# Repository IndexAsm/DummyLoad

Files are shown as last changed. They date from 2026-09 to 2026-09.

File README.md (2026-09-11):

# Electronic Load
A high-power, water-cooled electronic load designed for testing power supplies, batteries, converters, and other high-power electronics.

## [Board Preview]([https://kicanvas.org/?repo=https%3A%2F%2Fgithub.com%2FIndexAsm%2FDummyLoad](https://kicanvas.org/?repo=https%3A%2F%2Fgithub.com%2FIndexAsm%2FDummyLoad%2Ftree%2Fmain%2FPCB))
Note: There is a bug in the preview. It displays components from the control board next to power board, even though they are deleted in the project.

## Features
* **2 kW maximum power**
* **60 V maximum input voltage**
* **50 A maximum load current**
* **Water-cooled power stage**
* Constant-current (CC) regulation
* Multiple current ranges for improved resolution
* Designed for continuous high-power operation
* Custom-built control and measurement electronics

## Specifications

| Parameter | Specification |
| --- | ---: |
| Maximum Power | **2 kW** |
| Maximum Voltage | **60 V** |
| Maximum Current | **50 A** |
| Cooling | **Water cooling** |
| Regulation Mode | **Constant Current (CC)** |

### CC Regulation Ranges

| Current Range | Resolution |
| ---: | ---: |
| 0–50 A | 100 mA |
| 0–10 A | 25 mA |
| 0–5 A | 10 mA |

The selectable current ranges provide finer control at lower currents while maintaining the full **50 A** capability when required.

## Functions

* **Constant-current load (CC)**
* Selectable current ranges
* Input voltage measurement
* Load current measurement
* Power measurement
* Water-cooling system
* High-power continuous-load operation

## Applications

This electronic load is intended for testing:

* Linear and switching power supplies
* DC-DC converters
* Battery systems
* USB power supplies
* High-current power sources
* Custom power electronics

## [BOM](BOM.csv)
Total is around 600zł -> 160$

## Gallery
obraz
obraz

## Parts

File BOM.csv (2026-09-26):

Reference | Qty | Value | Price | Footprint | Link | DNP
C1,C3,C5,C14,C15,C17,C18,C21,C22,C23,C24,C25,C26,C28,C29,C30,C31,C32,C33,C36,C37,C40,C41,C42,C43,C44,C47,C48,C53,C54,C56,C58,C59 | 33 | 100n |  | Capacitor_SMD:C_0603_1608Metric
C2,C19,C27,C39 | 4 | 2u2 |  | Capacitor_SMD:C_0603_1608Metric
C4,C20 | 2 | 100u |  | Capacitor_THT:C_Radial_D6.3mm_H7.0mm_P2.50mm
C6,C62 | 2 | 22u | 4.10 | Capacitor_SMD:C_1206_3216Metric | https://www.tme.eu/pl/details/grm31cr61e226ke15l/kondensatory-mlcc-smd/murata/
C7 | 1 | 100n | 2.45 | Capacitor_THT:C_Disc_D11.0mm_W5.0mm_P10.00mm | https://www.tme.eu/pl/en/details/cc-104_500/ceramic-capacitors/sr-passives/
C8,C9,C10 | 3 | 1n |  | Capacitor_SMD:C_0603_1608Metric
C11,C12,C13 | 3 | 10n |  | Capacitor_SMD:C_0603_1608Metric
C16,C63,C64 | 3 | 100n |  | Capacitor_SMD:C_0603_1608Metric | https://www.tme.eu/pl/details/grm188r60j226mea0d/kondensatory-mlcc-smd/murata/
C34,C35 | 2 | 12p |  | Capacitor_SMD:C_0603_1608Metric
C38 | 1 | 10u | 1,51zł | Capacitor_SMD:C_0805_2012Metric | https://www.mouser.pl/en/ProductDetail/Samsung-Electro-Mechanics/CL21A106KOQNNNF
C45,C46,C49,C50,C51,C52,C55,C57,C60 | 9 | 22u | 9.83 | Capacitor_SMD:C_1206_3216Metric | https://www.tme.eu/pl/en/details/msast31lbb5226mtna/mlcc-smd-capacitors/taiyo-yuden/msast31lbb5226mtna01/
C61 | 1 | 22n |  | Capacitor_SMD:C_0603_1608Metric | https://www.tme.eu/pl/details/cc0603krx7r9bb223/kondensatory-mlcc-smd/yageo/
D1,D2 | 2 | 1N4148W |  | Diode_SMD:D_SOD-123
FB1,FB2 | 2 | 220R |  | Inductor_SMD:L_0603_1608Metric
FB3 | 1 | 120R |  | Inductor_SMD:L_0603_1608Metric
J1 | 8 | YK3030423000G | 57.07 | TerminalBlock_MetzConnect:TerminalBlock_MetzConnect_Type175_RT02704HBLC_1x04_P7.50mm_Horizontal | https://www.tme.eu/pl/en/details/yk3030423000g/terminal-blocks/amphenol-anytek/
J3,J4,J5,J6,J7 | 5 | Conn_01x10 |  | Connector_PinHeader_2.54mm:PinHeader_1x10_P2.54mm_Vertical
J8 | 1 | Conn_01x14 |  | Connector_PinHeader_2.54mm:PinHeader_1x14_P2.54mm_Vertical
J9,J11 | 2 | Conn_01x04 |  | Connector_PinHeader_2.54mm:PinHeader_1x04_P2.54mm_Vertical
J10 | 1 | Screw_Terminal_01x03 |  | Connector_PinHeader_2.54mm:PinHeader_1x03_P2.54mm_Vertical
J12 | 1 | USB4105-GF-A-120 | 3.43 | Connector_USB:USB_C_Receptacle_G-Switch_GT-USB-7010ASV | https://www.tme.eu/pl/details/usb4105-gf-a-120/zlacza-usb-i-ieee1394/gct/
J13 | 1 | Screw_Terminal_01x02 |  | TerminalBlock:TerminalBlock_MaiXu_MX126-5.0-02P_1x02_P5.00mm
K1 | 1 | G2RL-1-E | 69.0zł | Relay_THT:Relay_SPDT_Omron_G2RL-1-E | https://allegro.pl/produkt/przekaznik-mechaniczny-omron-g2r-1-e-24v-dc-f4f03ad2-a6c2-4227-9295-516ec5d28645?offerId=17156955515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
L1 | 1 | 15u | 3.19 | Inductor_SMD:L_APV_APH1240 | https://www.tme.eu/pl/en/details/dr127-150-r/inductors/eaton-electronics/
L2 | 1 | 4u7 | 10.04 | Inductor_SMD:L_APV_ANR5040 | https://www.tme.eu/pl/details/sdia0540mt4r7a/dlawiki/viking/
M1,M2,M3,M4 | 4 | Fan_4pin |  | Connector:FanPinHeader_1x04_P2.54mm_Vertical
Q1,Q2,Q3 | 12 | IRFP250N | 63.84 | Package_TO_SOT_THT:TO-247-3_Vertical | https://allegro.pl/oferta/2szt-tranzystor-irfp250n-n-mosfet-30a-200v-150w-to247ac-ir-15664037149
Q4 | 1 | 2N7002 |  | Package_TO_SOT_SMD:SOT-23
R1,R2,R3,R10,R14,R15 | 6 | 0R1 |  | Resistor_THT:R_Axial_DIN0617_L17.0mm_D6.0mm_P25.40mm_Horizontal | https://allegro.pl/produkt/rezystor-3w-0-1r-royal-ohm-knp-23c5e6cd-437c-4079-84cf-43188574fbc1?offerId=14745280089
R4,R5,R6,R19,R21,R22 | 6 | 4k7 |  | Resistor_SMD:R_0603_1608Metric
R7,R8,R9 | 3 | 220R |  | Resistor_SMD:R_0603_1608Metric
R11,R12,R13 | 3 | 1k |  | Resistor_SMD:R_0603_1608Metric
R16,R27,R36,R38,R40 | 5 | 100k |  | Resistor_SMD:R_0603_1608Metric
R17 | 1 | 0R01 | 33.16 | Resistor_THT:R_Bare_Metal_Element_L21.3mm_W4.8mm_P20.30mm | https://www.tme.eu/pl/en/details/oar5r010flf/power-resistors/tt-electronics/
R18 | 1 | 0R1 | 38.04 | Resistor_THT:R_Bare_Metal_Element_L21.3mm_W4.8mm_P20.30mm | https://www.tme.eu/pl/en/details/oar3r100flf/power-resistors/tt-electronics/
R20 | 1 | 1k5 |  | Resistor_SMD:R_0603_1608Metric
R23,R24,R26,R29,R30,R31,R32 | 7 | 10k |  | Resistor_SMD:R_0603_1608Metric
R25 | 1 | 0R |  | Resistor_SMD:R_0603_1608Metric
R28 | 1 | 100R |  | Resistor_SMD:R_0603_1608Metric
R33,R34,R35 | 3 | 5k1 |  | Resistor_SMD:R_0603_1608Metric
R37 | 1 | 46.40 |  | Resistor_SMD:R_0603_1608Metric
R39 | 1 | 22k |  | Resistor_SMD:R_0603_1608Metric
RV1,RV3,RV4,RV5 | 4 | 10k |  | Potentiometer_THT:Potentiometer_ACP_CA14-H5_Horizontal
RV2 | 1 | 50k |  | Potentiometer_THT:Potentiometer_ACP_CA14-H4_Horizontal
U1 | 1 | LM324 |  | Package_DIP:DIP-14_W7.62mm
U2 | 1 | ADS1115IDGS |  | Package_SO:TSSOP-10_3x3mm_P0.5mm
U3,U4 | 8 | INA180A1 | 14.34 | Package_TO_SOT_SMD:SOT-23-5 | https://www.tme.eu/pl/en/details/ina180a2idbvr/smd-operational-amplifiers/texas-instruments/
U5 | 1 | 74HC4051 | 1.52 | Package_SO:SOIC-16_3.9x9.9mm_P1.27mm | https://www.tme.eu/pl/en/details/74hc4051d.653/decoders-multiplexers-switches/nexperia/74hc4051d-653/
U6 | 1 | LMR33630ADDA | 13.43 | Package_SO:Texas_HSOP-8-1EP_3.9x4.9mm_P1.27mm_ThermalVias | https://www.tme.eu/pl/en/details/lmr33630adda/voltage-regulators-dc-dc-circuits/texas-instruments/
U7 | 1 | STM32G431C6Tx | 16,72zł | Package_QFP:LQFP-48_7x7mm_P0.5mm | https://www.mouser.pl/en/ProductDetail/STMicroelectronics/STM32G431C6T6?qs=uwxL4vQweFMIHkXLHKxSFQ%3D%3D
U8 | 1 | USBLC6-2SC6 |  | Package_TO_SOT_SMD:SOT-23-6
U9 | 1 | FM24C64B |  | Package_SO:SOIC-8_3.9x4.9mm_P1.27mm
U10 | 1 | TMP102xxDRL | 4,15zł | Package_TO_SOT_SMD:SOT-563 | https://www.mouser.pl/en/ProductDetail/Texas-Instruments/TMP102AQDRLRQ1?qs=asCBFxFfL1SM%2FKfsYcTt1w%3D%3D
U11 | 1 | L7815 | 4.47 | Package_TO_SOT_SMD:TO-252-2
U12 | 1 | MCP4728 | 10.86 | Package_SO:MSOP-10_3x3mm_P0.5mm | https://www.tme.eu/pl/en/details/mcp4728-e_un/d-a-converters-integrated-circuits/microchip-technology/
U13 | 1 | L7805 | 4.25 | Package_TO_SOT_SMD:TO-252-2 | https://www.tme.eu/pl/en/details/l7805cdt-tr/fixed-voltage-regulators/stmicroelectronics/
U14 | 1 | SD8942 |  | Package_TO_SOT_SMD:SOT-23-6 | https://allegrolokalnie.pl/oferta/konwerter-napiecia-dcdc-sd8942
Y1 | 1 | Crystal_GND24 | 0,87zł | Crystal:Crystal_SMD_EuroQuartz_X22-4Pin_2.5x2.0mm_HandSoldering | https://www.mouser.pl/en/ProductDetail/Eaton-Electronics/E2X160122X03?qs=%252BXxaIXUDbq2twjo5ayNDpw%3D%3D
AIO |  |  | 99.99 |  | https://allegro.pl/produkt/chlodzenie-wodne-msi-mag-coreliquid-360r-v2-d1a24009-753c-47a3-874d-db242f6ccd08?offerId=18857352469
PCB |  |  | $31.16
Total |  |  | 582,56zł | 156,26USD

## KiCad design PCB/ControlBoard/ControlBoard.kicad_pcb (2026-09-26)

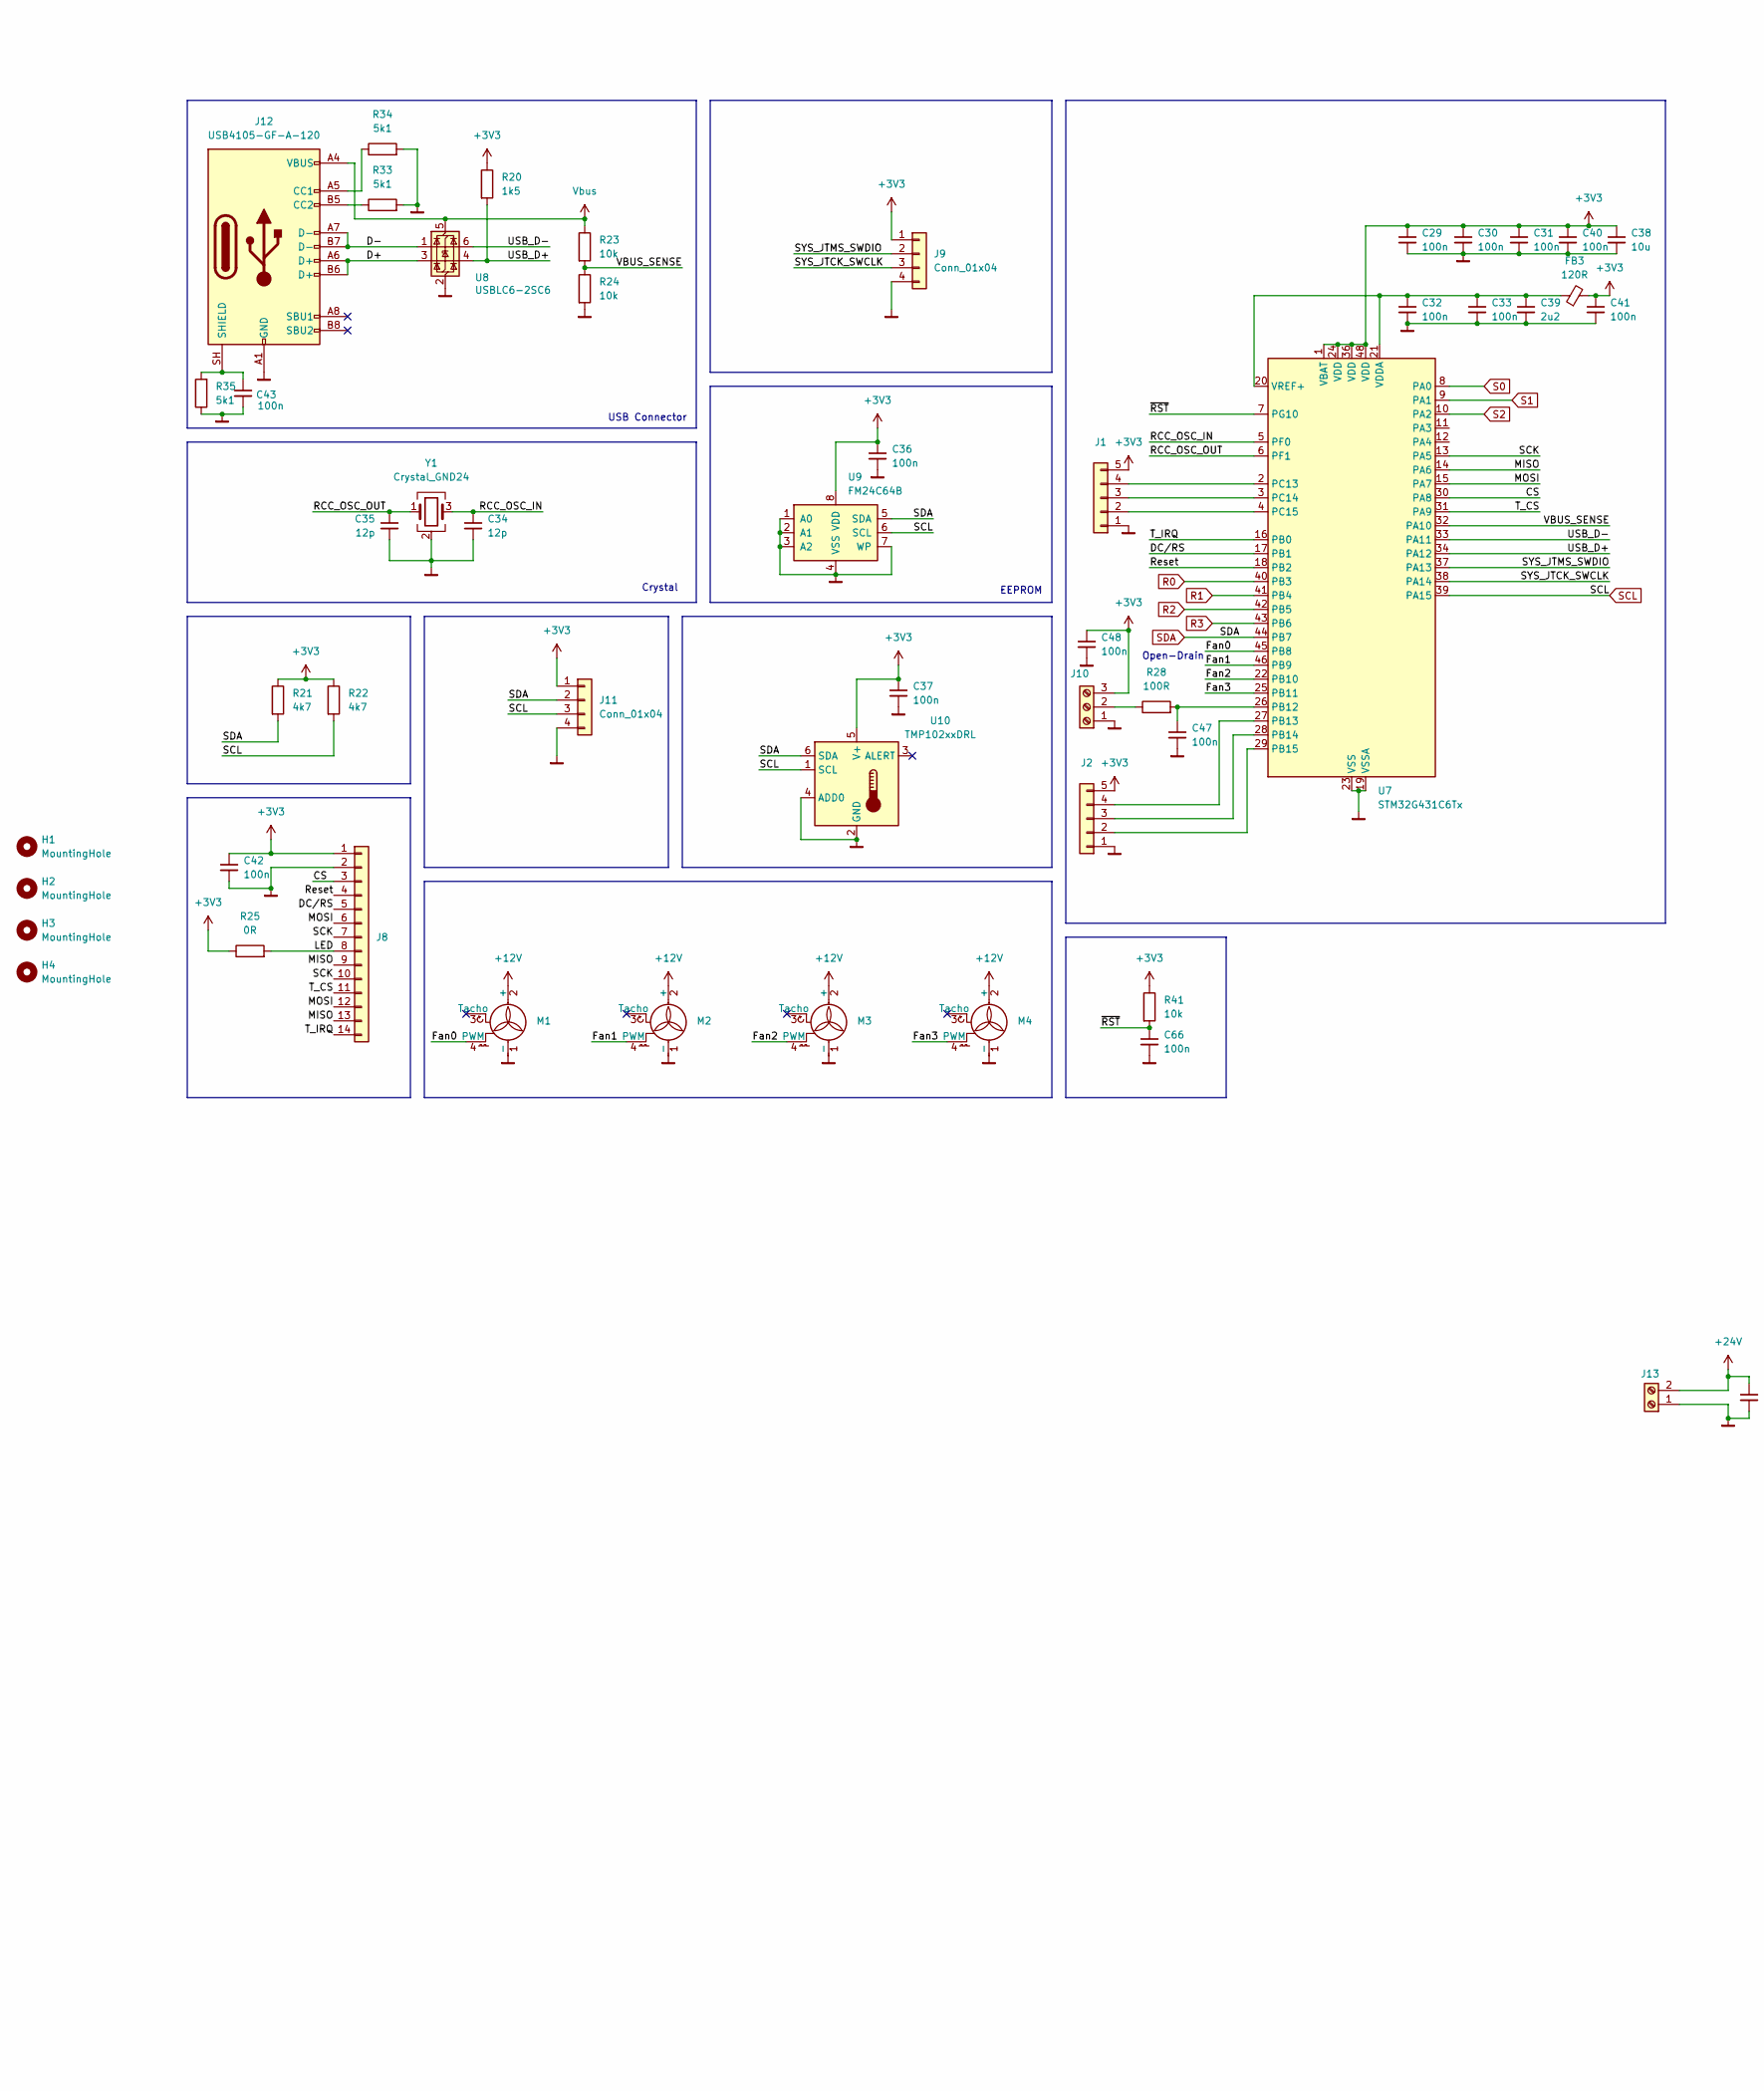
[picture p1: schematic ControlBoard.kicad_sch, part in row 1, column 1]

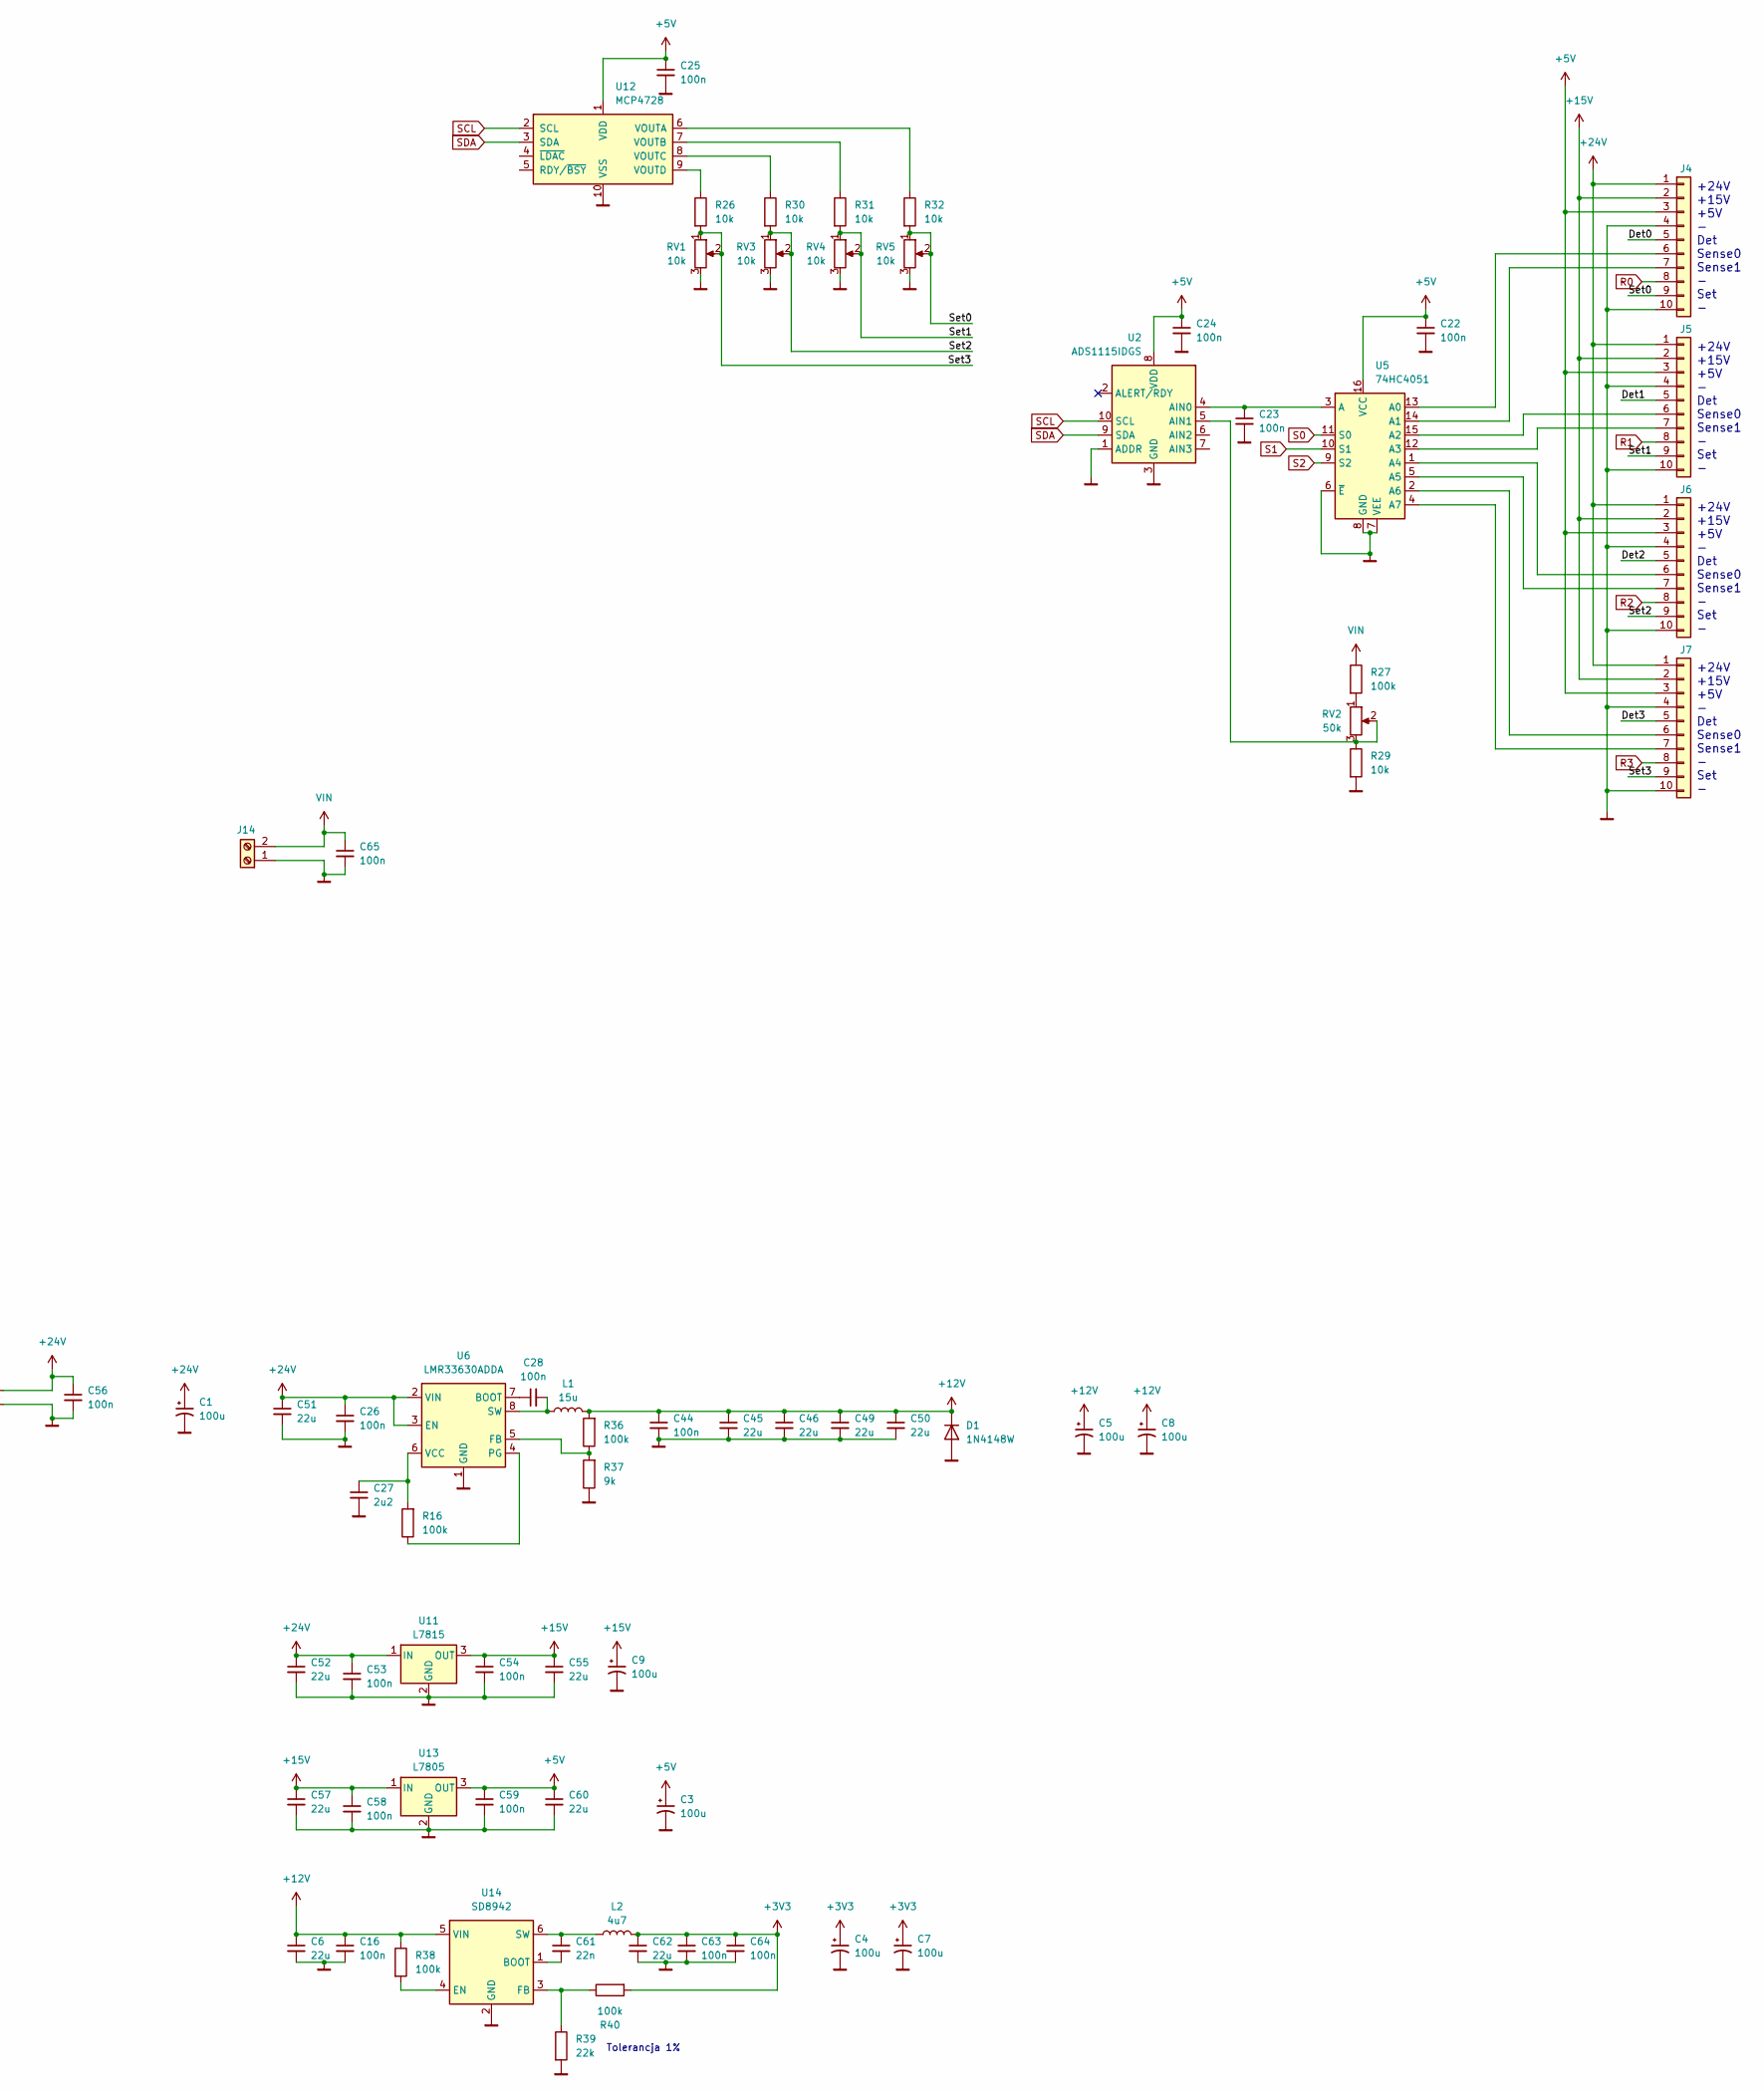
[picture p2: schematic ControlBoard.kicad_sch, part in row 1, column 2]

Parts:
C1, C3, C4, C5, C7, C8, C9: 100u; CP_Radial_D6.3mm_P2.50mm
C6, C45, C46, C49, C50, C51, C52, C55, C57, C60, C62: 22u; C_1206_3216Metric
C16, C22, C23, C24, C25, C26, C28, C29, C30, C31, C32, C33, C36, C37, C40, C41, C42, C43, C44, C47, C48, C53, C54, C56, C58, C59, C63, C64, C65, C66: 100n; C_0603_1608Metric
C27, C39: 2u2; C_0603_1608Metric
C34, C35: 12p; C_0603_1608Metric
C38: 10u; C_0805_2012Metric
C61: 22n; C_0603_1608Metric
D1: 1N4148W; D_SOD-123
FB3: 120R; L_0603_1608Metric
H1, H2, H3, H4: MountingHole; MountingHole_3.2mm_M3
J1, J2: Conn_01x05; PinHeader_1x05_P2.54mm_Vertical
J4, J5, J6, J7: Conn_01x10; PinHeader_1x10_P2.54mm_Vertical
J8: Conn_01x14; PinHeader_1x14_P2.54mm_Vertical
J9, J11: Conn_01x04; PinHeader_1x04_P2.54mm_Vertical
J10: Screw_Terminal_01x03; PinHeader_1x03_P2.54mm_Vertical
J12: USB4105-GF-A-120; USB_C_Receptacle_G-Switch_GT-USB-7010ASV
J13, J14: Screw_Terminal_01x02; TerminalBlock_MaiXu_MX126-5.0-02P_1x02_P5.00mm
L1: 15u; L_APV_APH1240
L2: 4u7; L_APV_ANR5040
M1, M2, M3, M4: Fan_4pin; FanPinHeader_1x04_P2.54mm_Vertical
R16, R27, R36, R38, R40: 100k; R_0603_1608Metric
R20: 1k5; R_0603_1608Metric
R21, R22: 4k7; R_0603_1608Metric
R23, R24, R26, R29, R30, R31, R32, R41: 10k; R_0603_1608Metric
R25: 0R; R_0603_1608Metric
R28: 100R; R_0603_1608Metric
R33, R34, R35: 5k1; R_0603_1608Metric
R37: 9k; R_0603_1608Metric
R39: 22k; R_0603_1608Metric
RV1, RV3, RV4, RV5: 10k; Potentiometer_Bourns_3296W_Vertical
RV2: 50k; Potentiometer_Bourns_3296W_Vertical
U2: ADS1115IDGS; TSSOP-10_3x3mm_P0.5mm
U5: 74HC4051; SOIC-16_3.9x9.9mm_P1.27mm
U6: LMR33630ADDA; Texas_HSOP-8-1EP_3.9x4.9mm_P1.27mm_ThermalVias
U7: STM32G431C6Tx; LQFP-48_7x7mm_P0.5mm
U8: USBLC6-2SC6; SOT-23-6
U9: FM24C64B; SOIC-8_3.9x4.9mm_P1.27mm
U10: TMP102xxDRL; SOT-563
U11: L7815; TO-252-2
U12: MCP4728; MSOP-10_3x3mm_P0.5mm
U13: L7805; TO-252-2
U14: SD8942; SOT-23-6
Y1: Crystal_GND24; Crystal_SMD_EuroQuartz_X22-4Pin_2.5x2.0mm_HandSoldering

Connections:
+3V3: C4.1, C7.1, C29.1, C30.1, C31.1, C36.1, C37.1, C38.1, C40.1, C41.1, C42.1, C48.1, C62.1, C63.1, C64.1, FB3.2, J1.5, J2.5, J8.1, J9.1, J10.3, J11.1, L2.2, R20.1, R21.1, R22.1, R25.1, R40.2, R41.1, U7.1 (VBAT), U7.24 (VDD), U7.36 (VDD), U7.48 (VDD), U9.8 (VDD), U10.5 (V+)
+5V: C3.1, C22.1, C24.1, C25.1, C59.1, C60.1, J4.3, J5.3, J6.3, J7.3, U2.8 (VDD), U5.16 (VCC), U12.1 (VDD), U13.3 (OUT)
+12V: C5.1, C6.1, C8.1, C16.1, C44.1, C45.1, C46.1, C49.1, C50.1, D1.1 (K), L1.2, M1.2 (+), M2.2 (+), M3.2 (+), M4.2 (+), R36.2, R38.1, U14.5 (VIN)
+15V: C9.1, C54.1, C55.1, C57.1, C58.1, J4.2, J5.2, J6.2, J7.2, U11.3 (OUT), U13.1 (IN)
+24V: C1.1, C26.1, C51.1, C52.1, C53.1, C56.1, J4.1, J5.1, J6.1, J7.1, J13.2, U6.2 (VIN), U6.3 (EN), U11.1 (IN)
/CS: J8.3, U7.30 (PA8)
/D+: J12.A6 (D+), J12.B6 (D+), U8.3 (I/O2)
/D-: J12.A7 (D-), J12.B7 (D-), U8.1 (I/O1)
/DC/RS: J8.5, U7.17 (PB1)
/Det0: J4.5
/Det1: J5.5
/Det2: J6.5
/Det3: J7.5
/Fan0: M1.4 (PWM), U7.45 (PB8)
/Fan1: M2.4 (PWM), U7.46 (PB9)
/Fan2: M3.4 (PWM), U7.22 (PB10)
/Fan3: M4.4 (PWM), U7.25 (PB11)
/LED: J8.8, R25.2
/MISO: J8.9, J8.13, U7.14 (PA6)
/MOSI: J8.6, J8.12, U7.15 (PA7)
/RCC_OSC_IN: C34.1, U7.5 (PF0), Y1.3
/RCC_OSC_OUT: C35.1, U7.6 (PF1), Y1.1
/Reset: J8.4, U7.18 (PB2)
/SCK: J8.7, J8.10, U7.13 (PA5)
/SYS_JTCK_SWCLK: J9.3, U7.38 (PA14)
/SYS_JTMS_SWDIO: J9.2, U7.37 (PA13)
/Set0: J4.9, R32.2, RV5.1, RV5.2
/Set1: J5.9, R31.2, RV4.1, RV4.2
/Set2: J6.9, R30.2, RV3.1, RV3.2
/Set3: J7.9, R26.2, RV1.1, RV1.2
/T_CS: J8.11, U7.31 (PA9)
/T_IRQ: J8.14, U7.16 (PB0)
/USB_D+: R20.2, U7.34 (PA12), U8.4 (I/O2)
/USB_D-: U7.33 (PA11), U8.6 (I/O1)
/VBUS_SENSE: R23.2, R24.1, U7.32 (PA10)
/~RST: C66.1, R41.2, U7.7 (PG10)
Masa: C1.2, C3.2, C4.2, C5.2, C6.2, C7.2, C8.2, C9.2, C16.2, C22.2, C23.2, C24.2, C25.2, C26.2, C27.2, C29.2, C30.2, C31.2, C32.2, C33.2, C34.2, C35.2, C36.2, C37.2, C38.2, C39.2, C40.2, C41.2, C42.2, C43.2, C44.2, C45.2, C46.2, C47.2, C48.2, C49.2, C50.2, C51.2, C52.2, C53.2, C54.2, C55.2, C56.2, C57.2, C58.2, C59.2, C60.2, C62.2, C63.2, C64.2, C65.2, C66.2, D1.2 (A), J1.1, J2.1, J4.4, J4.10, J5.4, J5.10, J6.4, J6.10, J7.4, J7.10, J8.2, J9.4, J10.1, J11.4, J12.A1 (GND), J12.A12 (GND), J12.B1 (GND), J12.B12 (GND), J13.1, J14.1, M1.1 (-), M2.1 (-), M3.1 (-), M4.1 (-), R24.2, R29.2, R33.2, R34.2, R35.1, R37.1, R39.2, RV1.3, RV3.3, RV4.3, RV5.3, U2.1 (ADDR), U2.3 (GND), U5.6 (~E), U5.7 (VEE), U5.8 (GND), U6.1 (GND), U6.9 (GND), U7.19 (VSSA), U7.23 (VSS), U7.35 (VSS), U7.47 (VSS), U8.2 (GND), U9.1 (A0), U9.2 (A1), U9.3 (A2), U9.4 (VSS), U9.7 (WP), U10.2 (GND), U10.4 (ADD0), U11.2 (GND), U12.10 (VSS), U13.2 (GND), U14.2 (GND), Y1.2 (G), Y1.4 (G)
unnamed: J1.2, U7.4 (PC15)
unnamed: J1.3, U7.3 (PC14)
unnamed: J1.4, U7.2 (PC13)
unnamed: J2.2, U7.29 (PB15)
unnamed: J2.3, U7.28 (PB14)
unnamed: J2.4, U7.27 (PB13)
unnamed: J4.6, U5.13 (A0)
unnamed: J4.7, U5.14 (A1)
unnamed: J5.6, U5.15 (A2)
unnamed: J5.7, U5.12 (A3)
unnamed: J6.6, U5.1 (A4)
unnamed: J6.7, U5.5 (A5)
unnamed: J7.6, U5.2 (A6)
unnamed: J7.7, U5.4 (A7)
unnamed: J10.2, R28.1
unnamed: J12.A5 (CC1), R34.1
unnamed: J12.B5 (CC2), R33.1
unnamed: C43.1, J12.SH (SHIELD), R35.2
unnamed: R27.2, RV2.1
unnamed: C23.1, U2.4 (AIN0), U5.3 (A)
unnamed: R29.1, RV2.2, RV2.3, U2.5 (AIN1)
unnamed: C28.1, U6.7 (BOOT)
unnamed: R36.1, R37.2, U6.5 (FB)
unnamed: R16.1, U6.4 (PG)
unnamed: C28.2, L1.1, U6.8 (SW)
unnamed: C27.1, R16.2, U6.6 (VCC)
unnamed: C47.1, R28.2, U7.26 (PB12)
unnamed: C32.1, C33.1, C39.1, FB3.1, U7.20 (VREF+), U7.21 (VDDA)
unnamed: R32.1, U12.6 (VOUTA)
unnamed: R31.1, U12.7 (VOUTB)
unnamed: R30.1, U12.8 (VOUTC)
unnamed: R26.1, U12.9 (VOUTD)
unnamed: C61.2, U14.1 (BOOT)
unnamed: R38.2, U14.4 (EN)
unnamed: R39.1, R40.1, U14.3 (FB)
unnamed: C61.1, L2.1, U14.6 (SW)
R0: J4.8, U7.40 (PB3)
R1: J5.8, U7.41 (PB4)
R2: J6.8, U7.42 (PB5)
R3: J7.8, U7.43 (PB6)
S0: U5.11 (S0), U7.8 (PA0)
S1: U5.10 (S1), U7.9 (PA1)
S2: U5.9 (S2), U7.10 (PA2)
SCL: J11.3, R22.2, U2.10 (SCL), U7.39 (PA15), U9.6 (SCL), U10.1 (SCL), U12.2 (SCL)
SDA: J11.2, R21.2, U2.9 (SDA), U7.44 (PB7), U9.5 (SDA), U10.6 (SDA), U12.3 (SDA)
VIN: C65.1, J14.2, R27.1
Vbus: J12.A4 (VBUS), J12.A9 (VBUS), J12.B4 (VBUS), J12.B9 (VBUS), R23.1, U8.5 (VBUS)

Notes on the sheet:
+24V +15V +5V - Det Sense0 Sense1 - Set -
Tolerancja 1%
Crystal
Open-Drain
USB Connector
EEPROM

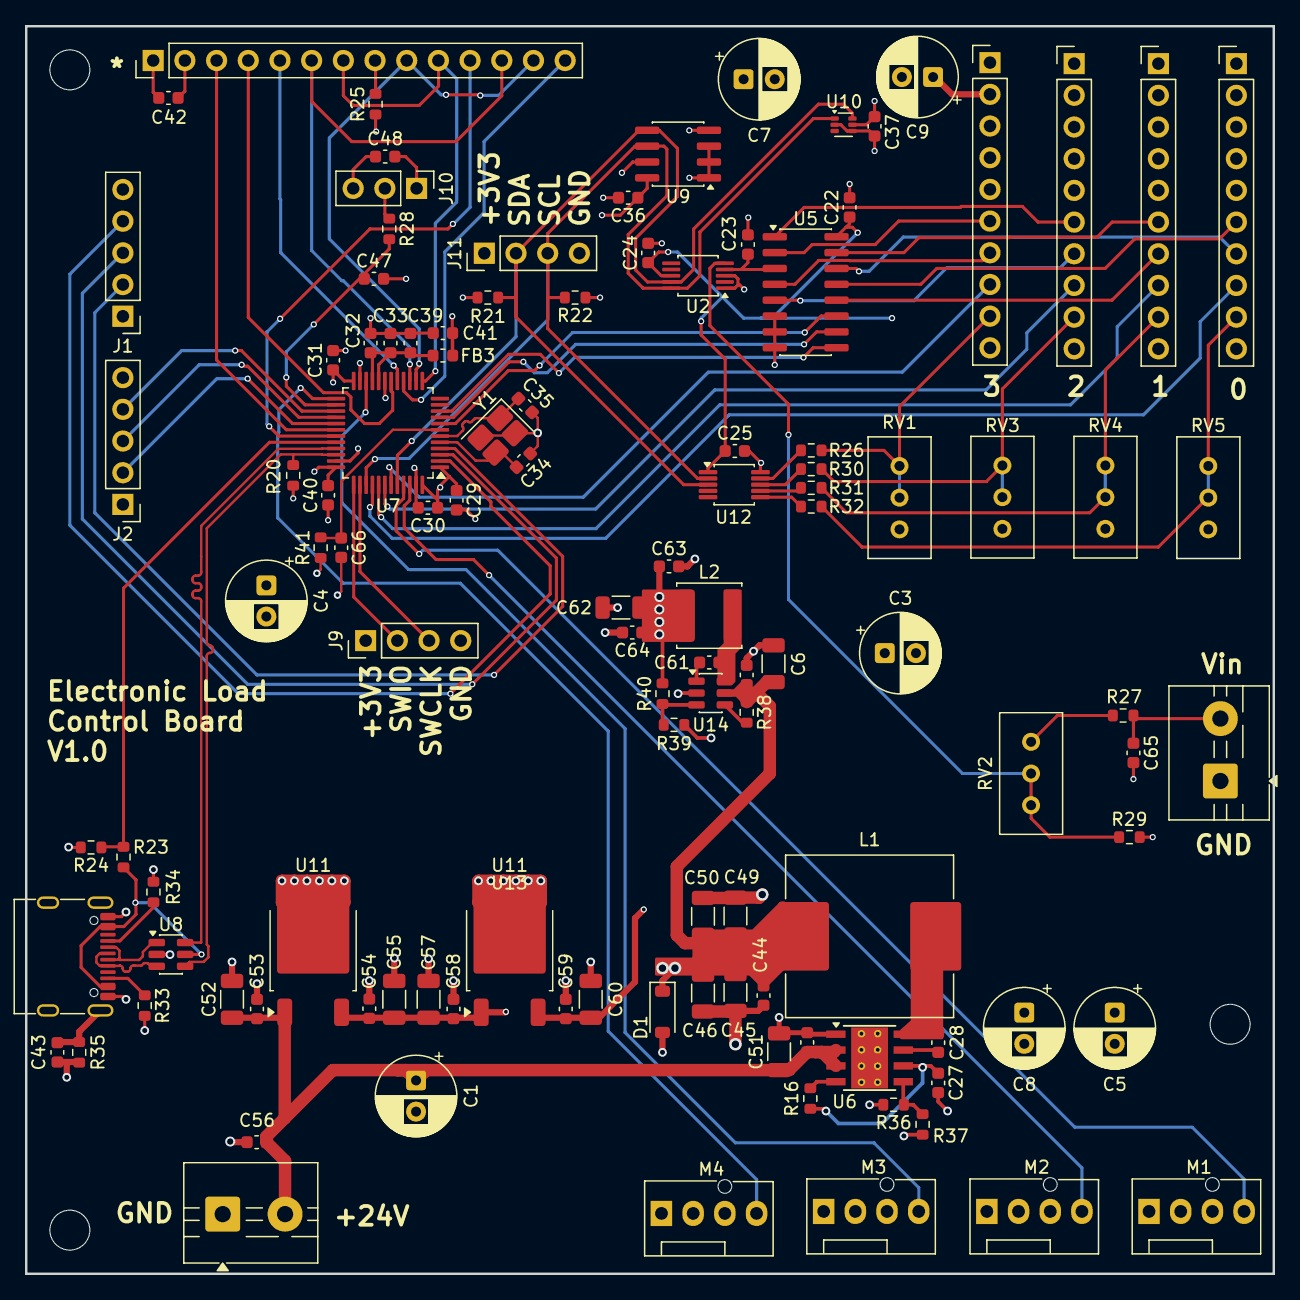
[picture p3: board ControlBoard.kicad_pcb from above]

Board: 4 copper layers, 100.0 x 100.0 mm, 117 parts (0 on the bottom side), 80 nets.

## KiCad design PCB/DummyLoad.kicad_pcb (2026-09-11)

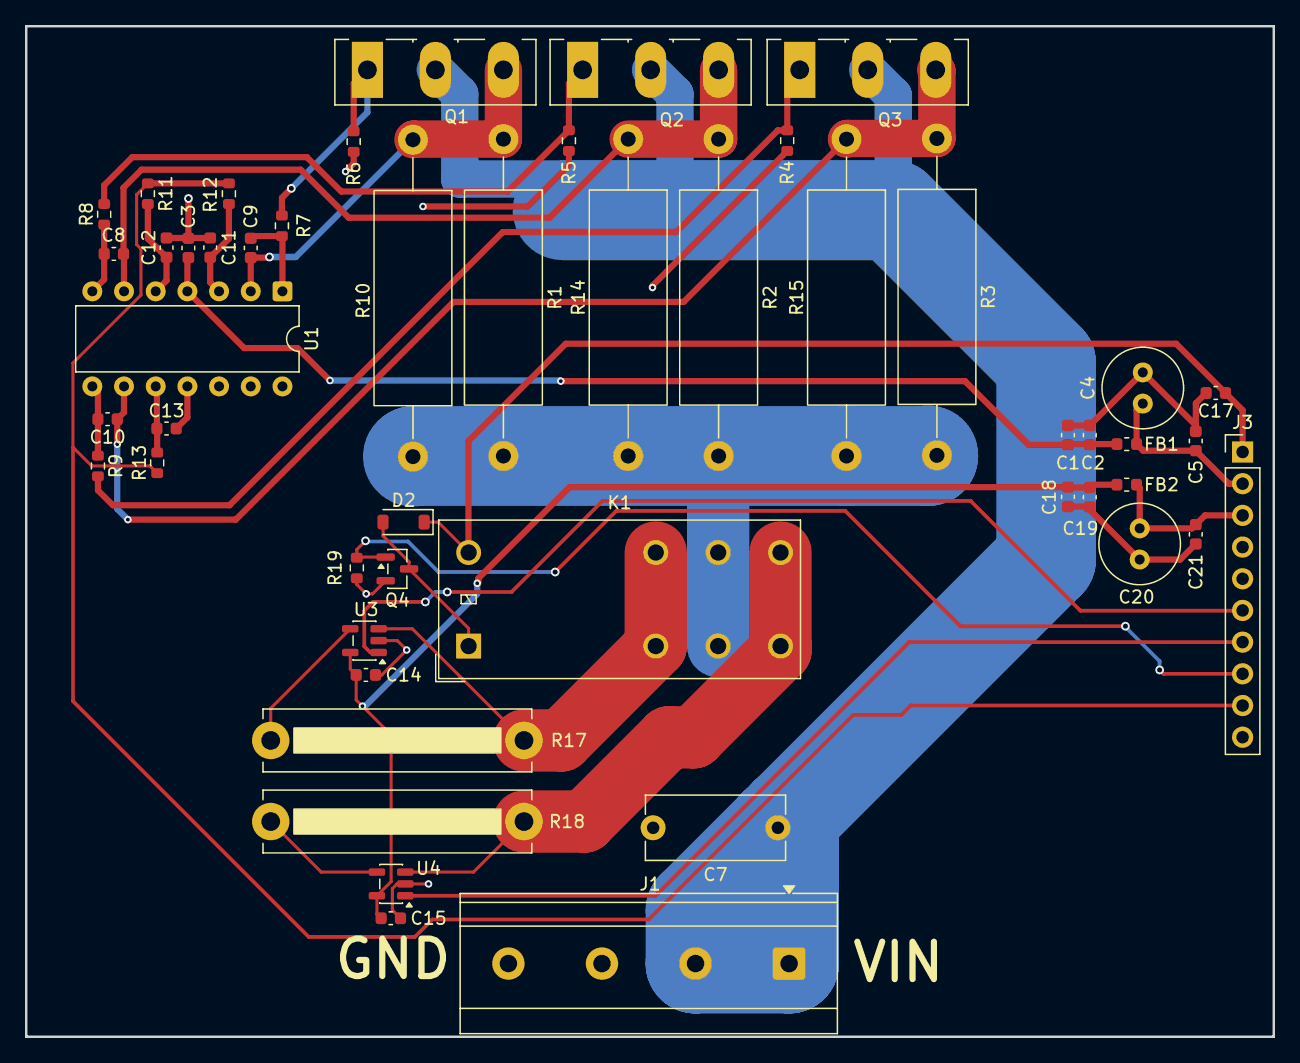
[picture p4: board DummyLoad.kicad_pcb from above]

Board: 2 copper layers, 100.0 x 81.0 mm, 50 parts (0 on the bottom side), 27 nets.

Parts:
C1, C3, C5, C14, C15, C17, C18, C21: 100n; C_0603_1608Metric
C2, C19: 2u2; C_0603_1608Metric
C4, C20: 100u; C_Radial_D6.3mm_H7.0mm_P2.50mm
C7: 100n; C_Disc_D11.0mm_W5.0mm_P10.00mm
C8, C9, C10: 1n; C_0603_1608Metric
C11, C12, C13: 10n; C_0603_1608Metric
D2: 1N4148W; D_SOD-123
FB1, FB2: 220R; L_0603_1608Metric
J1: YK3030423000G; TerminalBlock_MetzConnect_Type175_RT02704HBLC_1x04_P7.50mm_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
J3: Conn_01x10; PinHeader_1x10_P2.54mm_Vertical
K1: G2RL-1-E; Relay_SPDT_Omron_G2RL-1-E
Q1, Q2, Q3: IRFP250N; TO-247-3_Vertical
Q4: 2N7002; SOT-23
R1, R2, R3, R10, R14, R15: 0R1; R_Axial_DIN0617_L17.0mm_D6.0mm_P25.40mm_Horizontal
R4, R5, R6, R19: 4k7; R_0603_1608Metric
R7, R8, R9: 220R; R_0603_1608Metric
R11, R12, R13: 1k; R_0603_1608Metric
R17: 0R01; R_Bare_Metal_Element_L21.3mm_W4.8mm_P20.30mm
R18: 0R1; R_Bare_Metal_Element_L21.3mm_W4.8mm_P20.30mm
U1: LM324; DIP-14_W7.62mm
U3, U4: INA180A1; SOT-23-5

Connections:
+5V: C14.1, C15.1, C18.1, C19.1, FB2.1, U3.5 (V+), U4.5 (V+)
+15V: C1.1, C2.1, C3.1, FB1.1, U1.4 (V+)
+24V: C17.1, D2.1 (K), J3.1, K1.A2
/F0: C9.1, Q1.3 (S), R1.1, R10.1, U1.2 (-)
/F1: C8.1, Q2.3 (S), R2.1, R14.1, U1.6 (-)
/F2: C10.1, Q3.3 (S), R3.1, R15.1, U1.9 (-)
/G0: Q1.1 (G), R6.1, R7.2
/G1: Q2.1 (G), R5.1, R8.2
/G2: Q3.1 (G), R4.1, R9.2
/RangeSelect: J3.8, Q4.1 (G), R19.1
/Sense0: J3.6, U3.1
/Sense1: J3.7, U4.1
/Set: J3.9, R11.1, R12.1, R13.1
Masa: C1.2, C2.2, C3.2, C4.2, C5.2, C7.2, C11.2, C12.2, C13.2, C14.2, C15.2, C17.2, C18.2, C19.2, C20.2, C21.2, J1.3, J1.4, J3.4, J3.5, J3.10, Q4.2 (S), R4.2, R5.2, R6.2, R17.2, R18.2, R19.2, U1.11 (V-), U3.2 (GND), U3.4 (-), U4.2 (GND), U4.4 (-)
unnamed: C8.2, R8.1, U1.7
unnamed: C9.2, R7.1, U1.1
unnamed: C10.2, R9.1, U1.8
unnamed: D2.2 (A), K1.A1, Q4.3 (D)
unnamed: C4.1, C5.1, FB1.2, J3.2
unnamed: C20.1, C21.1, FB2.2, J3.3
unnamed: K1.11, R1.2, R2.2, R3.2, R10.2, R14.2, R15.2
unnamed: C11.1, R12.2, U1.3 (+)
unnamed: C12.1, R11.2, U1.5 (+)
unnamed: C13.1, R13.2, U1.10 (+)
unnamed: K1.12, R17.1, U3.3 (+)
unnamed: K1.14, R18.1, U4.3 (+)
VIN: C7.1, J1.1, J1.2, Q1.2 (D), Q2.2 (D), Q3.2 (D)

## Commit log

2026-08-22 Added README.md
    [ControlBoard.kicad_sch, DummyLoad.kicad_pcb, DummyLoad.kicad_sch]
2026-09-11 Update README with BOM and Gallery sections
    Added BOM section and Gallery with images to README.
2026-09-11 Fix link to BOM file in README
2026-09-11 Update README with total cost estimate
    Added total cost estimate in the BOM section.
2026-09-26 Fixed MCU Reset Line
    [ControlBoard.kicad_pcb, ControlBoard.kicad_sch]
2026-09-26 Fix formatting and add missing commas in BOM.csv
    [BOM.csv]
